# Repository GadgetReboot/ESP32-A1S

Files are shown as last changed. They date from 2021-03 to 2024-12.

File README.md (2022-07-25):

# ESP32-A1S
Breakout PCB for the ESP32-A1S module including an audio amp and basic GPIO headers, USB interface  
In Arduino IDE, the ESP32 board to choose is "ESP32 Dev Module"  
Use default configuration settings  
Then Enable PSRAM  <BR><BR>
The USB Micro-B connector on the board is GCT p/n USB3076-30-A   available from Digikey, Mouser etc

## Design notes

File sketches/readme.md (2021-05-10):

demo sketches to test EPS32-A1S module breakout board

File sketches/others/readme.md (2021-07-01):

Here are sketches that may be helpful to some, as presented here:<br>
https://github.com/GadgetReboot/ESP32-A1S/issues/1

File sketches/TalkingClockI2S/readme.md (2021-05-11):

ESP32 talking clock using the Talkie library to get the time over WiFi and speak it on the I2S audio chip

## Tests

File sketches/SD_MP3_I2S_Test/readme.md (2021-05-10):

List files on SD card and play mp3 files from root directory

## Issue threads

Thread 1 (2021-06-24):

Not an issue.

MichaelPNolan, 2021-06-24:
More like I want to say this was very helpful ... and I wish there was a place where I could link for others who want to learn using your code. I have written a more feature rich player moving on from the parts you put together to test playing mp3 from the card. Wondering if sharing my code so it's another sketch in your project is easier for others to find than trying to do my own video/links/github.

GadgetReboot, 2021-06-25:
> More like I want to say this was very helpful ... and I wish there was a place where I could link for others who want to learn using your code. I have written a more feature rich player moving on from the parts you put together to test playing mp3 from the card. Wondering if sharing my code so it's another sketch in your project is easier for others to find than trying to do my own video/links/github.

I'm glad it was helpful!  If you have a working demo sketch I could add it to the project examples for people to learn from.

MichaelPNolan, 2021-06-26:
Great - I've got a hack/continuation of your work
[SD_MP3_I2S_Hack02 .ino.txt](https://github.com/GadgetReboot/ESP32-A1S/files/6720121/SD_MP3_I2S_Hack02.ino.txt)
Rename to .ino
This a Hack02 version that can do FLAC and MP3 but the FLAC doesn't really work properly, its too slow ... or has noise. At least with the files I've tried so far. Something mentioned about running flac->loop(); to give it additional time to protest during the main program loop was mentioned. https://www.gitmemory.com/issue/earlephilhower/ESP8266Audio/301/686562378
That is where I was at when I uploaded.

There was a version before it that was just doing MP3 ...
[SD_MP3_I2S_Hack01.ino.txt](https://github.com/GadgetReboot/ESP32-A1S/files/6720123/SD_MP3_I2S_Hack01.ino.txt)
It might help people who want to make a music player. Best case for me is that ... more libraries get extended or ported from expressif ADF/IDF that might work. I've not made libraries in Arduino yet.

About me: I'm 52 and I started coding when I was 9. That doesn't mean I'm good at it - but i've been hacking this and that all my life in IT job. I was a musician as a trade for good portion of my life too ... which explains why I'm not a pro-software engineer.
I'm also making circuits but I've only ever done one PCB order from China for a pre-amp. I'm working on a headphone amp PCB .. and this is what leads me to an interest in DAC. I'm looking at making a midi master USB interface so I can play with the Marcel LIcence software and make hacks of that and ultimately I'd like to make a kind of hacked toy keyboard with a board in it that can be updated by wifi. I've written a VU meter for a single row of neopixel that takes a spectrum analysis fft but its a bit of a kludge. I'm usually trying to bring together past projects to make something that does everything.
I also do make videos on youtube but only getting started with any project like vids. Usually I just talk or make a lazy film of something I made to show friends.

I tried to make IDF/ADF environment work with my AI Thinker board but it just never really compiled for anything related to DAC. Too much time wasted. I had issues with Arduino until I really simplifed my library directory to just the least number of files for this to work. A lot of multiple library files errors before I did that.

GadgetReboot, 2021-07-01:
I've added the files here with a reference link back to this thread if it's useful to people
https://github.com/GadgetReboot/ESP32-A1S/tree/main/sketches/others
I will eventually try midi related things and I have several keyboards I can experiment with.

I'll probably make a pcb with a midi connector and isolation interface that can be connected to an Arduino as needed without dedicating it to a specific one so there's more flexibility.
20 years ago I'd probably be satisfied trying to place wires into midi connector pins and hope it holds up.

MichaelPNolan, 2021-07-01:
Thanks for that - yes, i had the pin connect hack days. I'm going to make my own arduino knock off before I try to implement something like an ESP32 dev board ... and I don't know where to start with surface mount and goo. That's why some of us have this mostly unsupported ESP32-A1S dev board. I've ordered some 16 bit DAC things so I can try with other boards sans AC101.

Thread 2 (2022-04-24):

Error in compiling

S144S, 2022-04-24:
Hi
Thanks for your helpful repo.
I was trying to test the example SD_MP3_I2S_TEST and I got this error:
"Error compiling for board ESP32 Dev Module."
I installed all required libraries, but I don't know where is the problem

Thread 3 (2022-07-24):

USB socket

bench2012, 2022-07-24:
Hi,

First of thanks for a very interesting board. I was going the same way, when I came across your project on GitHub. I managed to make a few board, but since there is no BOM list, just wonder which and where you got the usb socket? Usb socket could be a real pain to get right.

Many thx.

Bench

GadgetReboot, 2022-07-25:
The USB Micro-B connector on the board is GCT p/n USB3076-30-A   available from Digikey, Mouser etc

bench2012, 2022-07-25:
> The USB Micro-B connector on the board is GCT p/n USB3076-30-A available from Digikey, Mouser etc

Many thx. Will let you know how I get with this project. Again thanks for designing the board.

Closed 2022-07-25.

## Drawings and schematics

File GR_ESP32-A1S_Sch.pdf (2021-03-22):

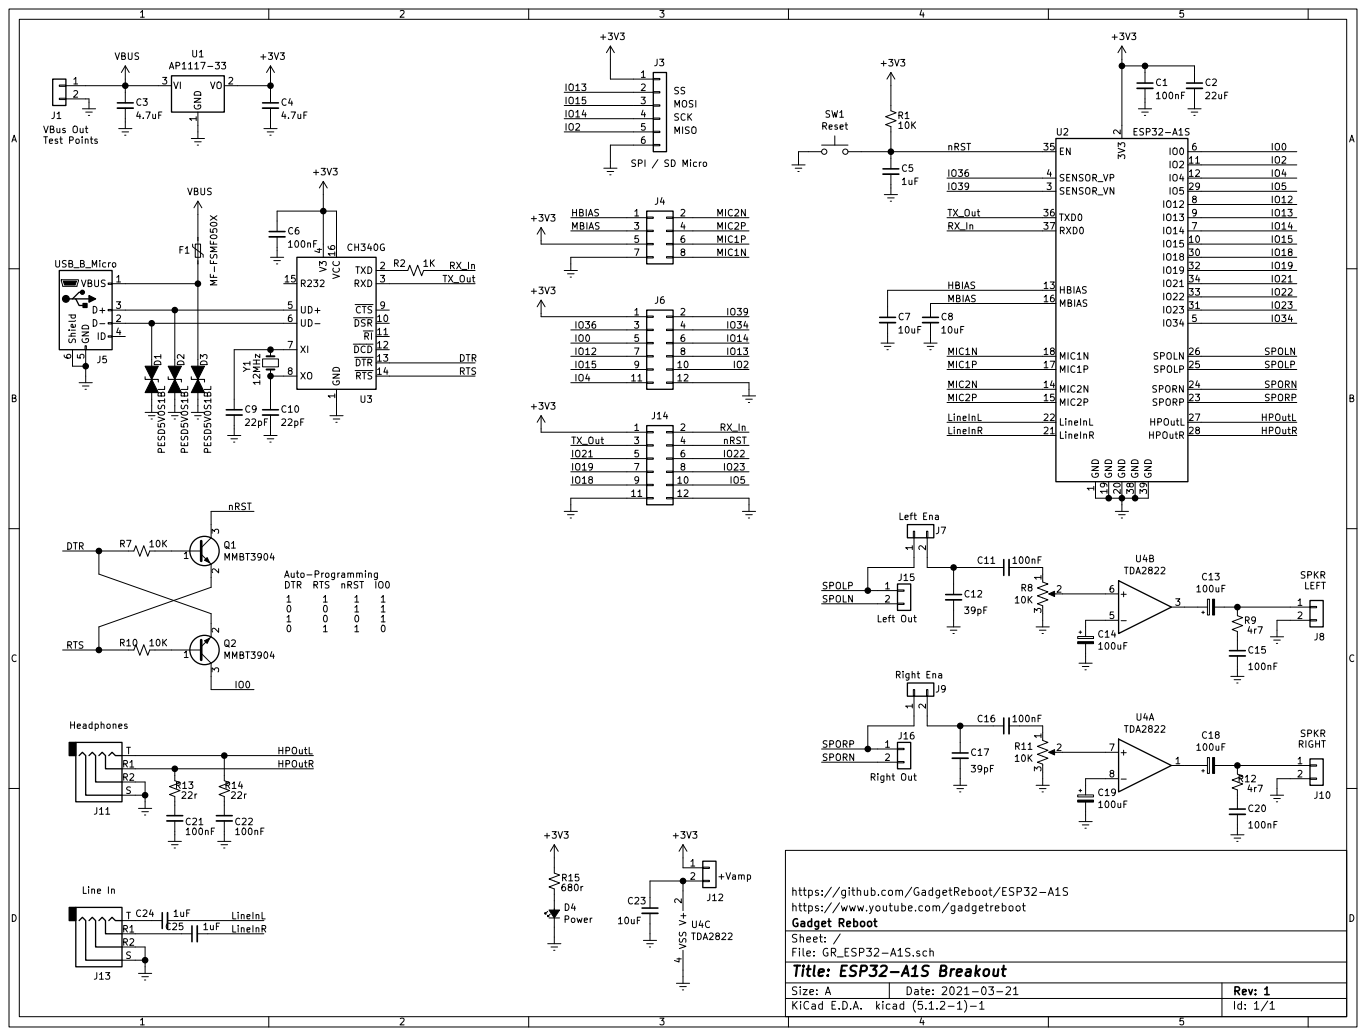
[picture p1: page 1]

1uF Auto-Programming DTR RTS nRST IO0

4 UD+ 5 UD- 6 XI 7 XO 8 CTS 9 U3 CH340G

1 DSR 10 RI 11 DCD 12 DTR 13 RTS 14 R232 15 VCC 16 TXD 2 RXD 3 V3

Left Ena Right Ena

Left Out Right Out

https://www.youtube.com/gadgetreboot
File: GR_ESP32-A1S.sch Sheet: / Gadget Reboot

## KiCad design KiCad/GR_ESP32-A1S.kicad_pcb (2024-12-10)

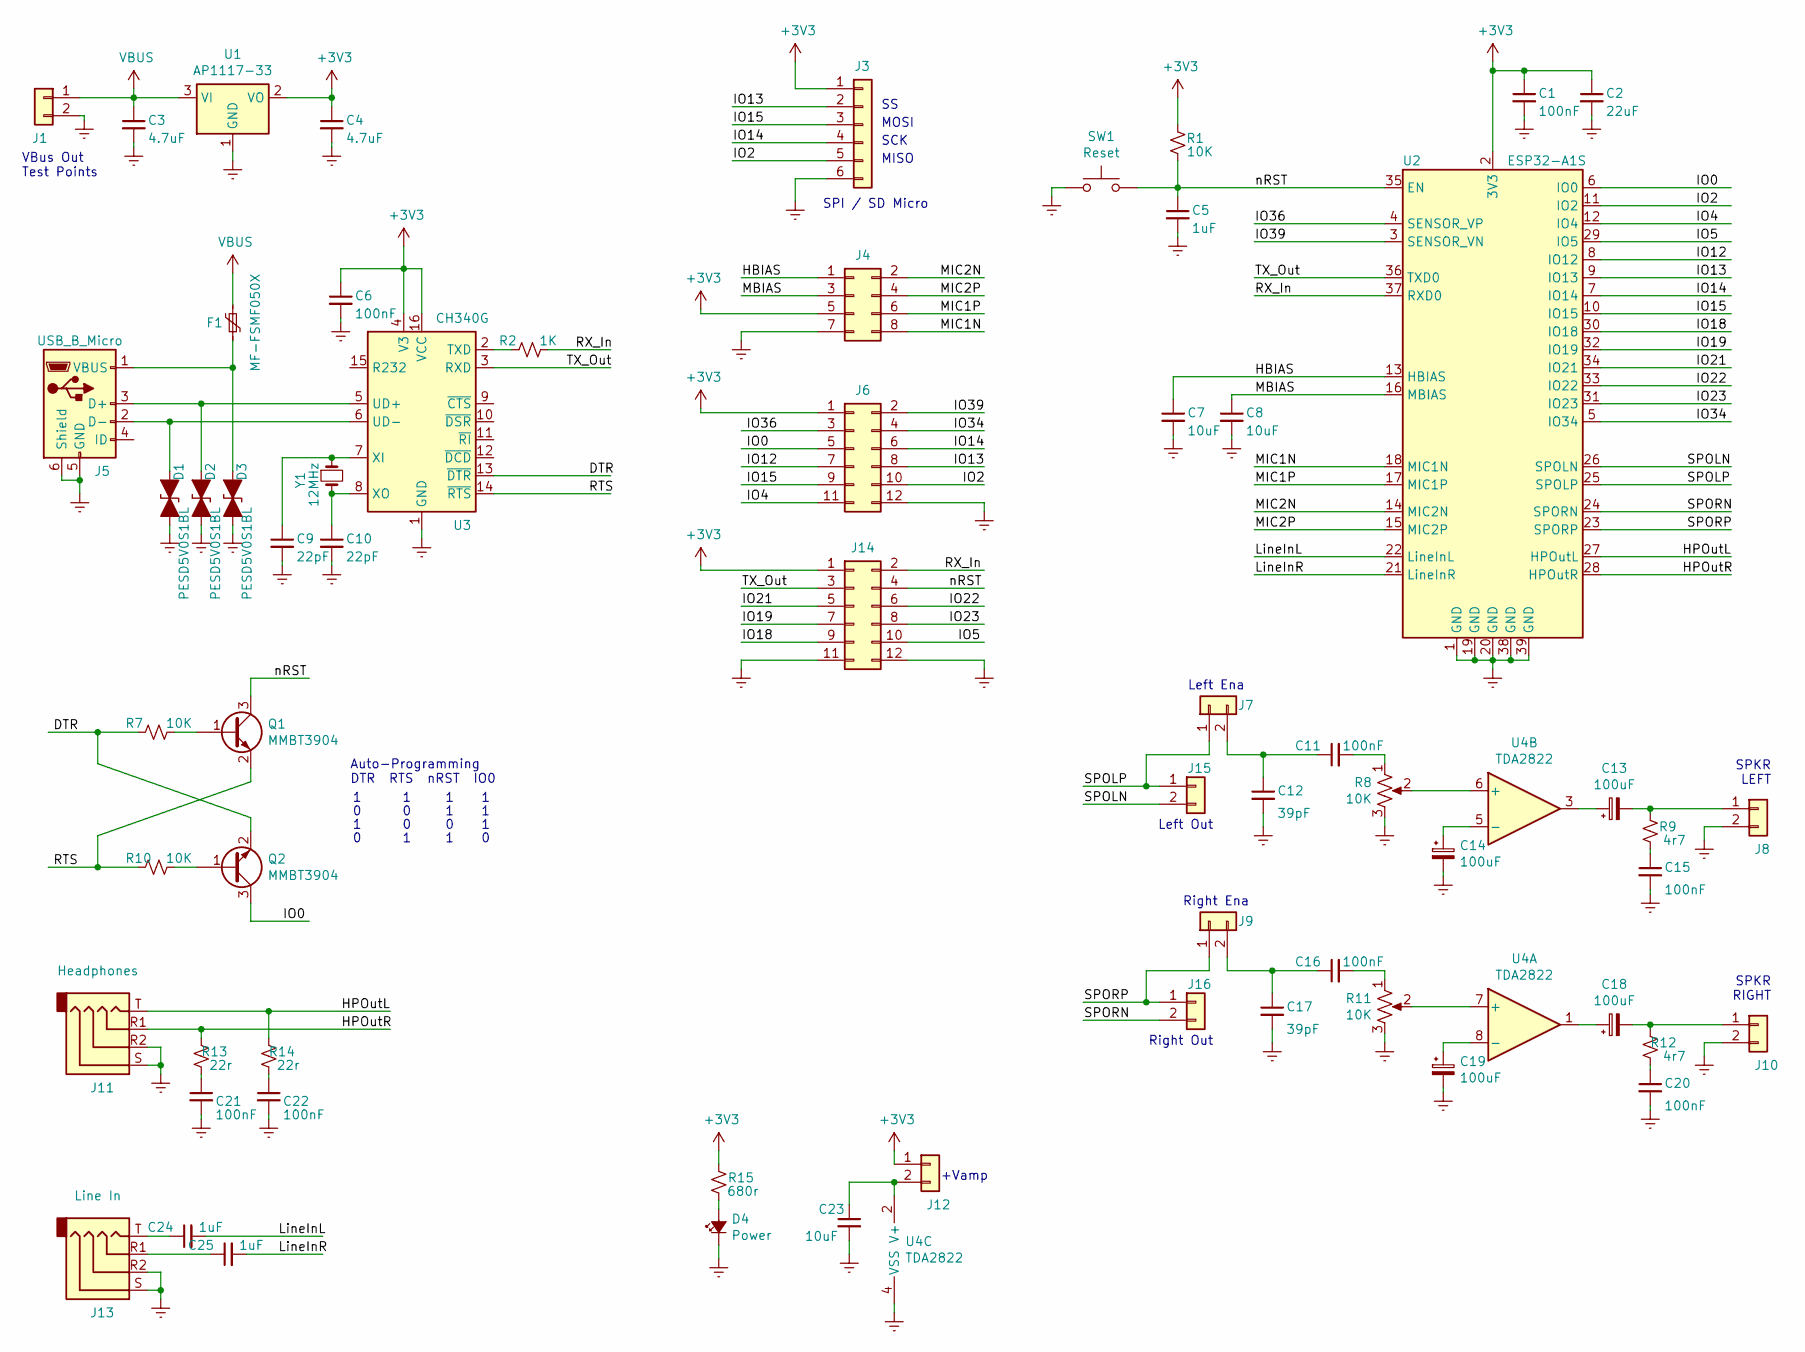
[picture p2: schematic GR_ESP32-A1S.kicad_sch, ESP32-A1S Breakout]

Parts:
C1, C6, C11, C15, C16, C20, C21, C22: 100nF; C_0805_2012Metric_Pad1.15x1.40mm_HandSolder
C2: 22uF; C_0805_2012Metric_Pad1.15x1.40mm_HandSolder
C3, C4: 4.7uF; C_0805_2012Metric_Pad1.15x1.40mm_HandSolder
C5, C24, C25: 1uF; C_0805_2012Metric_Pad1.15x1.40mm_HandSolder
C7, C8, C23: 10uF; C_0805_2012Metric_Pad1.15x1.40mm_HandSolder
C9, C10: 22pF; C_0805_2012Metric_Pad1.15x1.40mm_HandSolder
C12, C17: 39pF; C_0805_2012Metric_Pad1.15x1.40mm_HandSolder
C13, C14, C18, C19: 100uF; CP_Radial_D5.0mm_P2.50mm
D1, D2, D3: PESD5V0S1BL; SOD-882
D4: Power; LED_0805_2012Metric_Pad1.15x1.40mm_HandSolder
F1: MF-FSMF050X; R_0603_1608Metric_Pad1.05x0.95mm_HandSolder
J1, J7, J8, J9, J10, J12, J15, J16: Conn_01x02; PinHeader_1x02_P2.54mm_Vertical
J3: SPI; PinHeader_1x06_P2.54mm_Vertical
J4: Conn_02x04_Odd_Even; PinHeader_2x04_P2.54mm_Vertical
J5: USB_B_Micro; USB_Micro-B_GCT_USB3076-30-A
J6, J14: Conn_02x06_Odd_Even; PinHeader_2x06_P2.54mm_Vertical
J11: Headphones; Jack_3.5mm_PJ320D_Horizontal
J13: Line In; Jack_3.5mm_PJ320D_Horizontal
Q1, Q2: MMBT3904; SOT-23
R1, R7, R10: 10K; R_0805_2012Metric_Pad1.15x1.40mm_HandSolder
R2: 1K; R_0805_2012Metric_Pad1.15x1.40mm_HandSolder
R8, R11: 10K; Potentiometer_Vishay_T73YP_Vertical
R9, R12: 4r7; R_0805_2012Metric_Pad1.15x1.40mm_HandSolder
R13, R14: 22r; R_0805_2012Metric_Pad1.15x1.40mm_HandSolder
R15: 680r; R_0805_2012Metric_Pad1.15x1.40mm_HandSolder
SW1: Reset; SW_SPST_FSMSM
U1: AP1117-33; SOT-223-3_TabPin2
U2: ESP32-A1S
U3: CH340G; SOIC-16_3.9x9.9mm_P1.27mm
U4: TDA2822; SOIC-8_3.9x4.9mm_P1.27mm
Y1: 12MHz; Crystal_SMD_HC49-SD_HandSoldering

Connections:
+3V3: C1.1, C2.1, C4.1, C6.1, J3.1, J4.5, J6.1, J12.1, J14.1, R1.1, R15.1, U1.2 (VO), U2.2 (3V3), U3.4 (V3), U3.16 (VCC)
/DTR: Q2.2 (E), R7.1, U3.13 (~DTR)
/HBIAS: C7.1, J4.1, U2.13 (HBIAS)
/HPOutL: J11.T, R14.1, U2.27 (HPOutL)
/HPOutR: J11.R1, R13.1, U2.28 (HPOutR)
/IO0: J6.5, Q2.3 (C), U2.6 (IO0)
/IO2: J3.5, J6.10, U2.11 (IO2)
/IO4: J6.11, U2.12 (IO4)
/IO5: J14.10, U2.29 (IO5)
/IO12: J6.7, U2.8 (IO12)
/IO13: J3.2, J6.8, U2.9 (IO13)
/IO14: J3.4, J6.6, U2.7 (IO14)
/IO15: J3.3, J6.9, U2.10 (IO15)
/IO18: J14.9, U2.30 (IO18)
/IO19: J14.7, U2.32 (IO19)
/IO21: J14.5, U2.34 (IO21)
/IO22: J14.6, U2.33 (IO22)
/IO23: J14.8, U2.31 (IO23)
/IO34: J6.4, U2.5 (IO34)
/IO36: J6.3, U2.4 (SENSOR_VP)
/IO39: J6.2, U2.3 (SENSOR_VN)
/LineInL: C24.2, U2.22 (LineInL)
/LineInR: C25.2, U2.21 (LineInR)
/MBIAS: C8.1, J4.3, U2.16 (MBIAS)
/MIC1N: J4.8, U2.18 (MIC1N)
/MIC1P: J4.6, U2.17 (MIC1P)
/MIC2N: J4.2, U2.14 (MIC2N)
/MIC2P: J4.4, U2.15 (MIC2P)
/RTS: Q1.2 (E), R10.1, U3.14 (~RTS)
/RX_In: J14.2, R2.2, U2.37 (RXD0)
/SPOLN: J15.2, U2.26 (SPOLN)
/SPOLP: J7.1, J15.1, U2.25 (SPOLP)
/SPORN: J16.2, U2.24 (SPORN)
/SPORP: J9.1, J16.1, U2.23 (SPORP)
/TX_Out: J14.3, U2.36 (TXD0), U3.3 (RXD)
/nRST: C5.1, J14.4, Q1.3 (C), R1.2, SW1.2, U2.35 (EN)
GNDREF: C1.2, C2.2, C3.2, C4.2, C5.2, C6.2, C7.2, C8.2, C9.2, C10.2, C12.2, C14.2, C15.2, C17.2, C19.2, C20.2, C21.2, C22.2, C23.2, D1.2 (A2), D2.2 (A2), D3.2 (A2), D4.1 (K), J1.2, J3.6, J4.7, J5.5 (GND), J5.6 (Shield), J6.12, J8.2, J10.2, J11.R2, J11.S, J13.R2, J13.S, J14.11, J14.12, R8.3, R11.3, SW1.1, U1.1 (GND), U2.1 (GND), U2.19 (GND), U2.20 (GND), U2.38 (GND), U2.39 (GND), U3.1 (GND), U4.4 (VSS)
unnamed: C9.1, U3.7 (XI), Y1.1
unnamed: C10.1, U3.8 (XO), Y1.2
unnamed: C11.1, C12.1, J7.2
unnamed: C11.2, R8.1
unnamed: C13.1, U4.3
unnamed: C13.2, J8.1, R9.1
unnamed: C14.1, U4.5 (-)
unnamed: C15.1, R9.2
unnamed: C16.1, C17.1, J9.2
unnamed: C16.2, R11.1
unnamed: C18.1, U4.1
unnamed: C18.2, J10.1, R12.1
unnamed: C19.1, U4.8 (-)
unnamed: C20.1, R12.2
unnamed: C21.1, R13.2
unnamed: C22.1, R14.2
unnamed: C23.1, J12.2, U4.2 (V+)
unnamed: C24.1, J13.T
unnamed: C25.1, J13.R1
unnamed: D1.1 (A1), J5.2 (D-), U3.6 (UD-)
unnamed: D2.1 (A1), J5.3 (D+), U3.5 (UD+)
unnamed: D4.2 (A), R15.2
unnamed: Q1.1 (B), R7.2
unnamed: Q2.1 (B), R10.2
unnamed: R2.1, U3.2 (TXD)
unnamed: R8.2, U4.6 (+)
unnamed: R11.2, U4.7 (+)

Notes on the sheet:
Left Out
1 0 0 1
Right Ena
SPKR RIGHT
SPKR LEFT
SPI / SD Micro
Right Out
+Vamp
MISO
0 0 1 1
1 1 1 1
MOSI
Auto-Programming DTR RTS nRST IO0
Left Ena
SCK
0 1 1 0
VBus Out Test Points

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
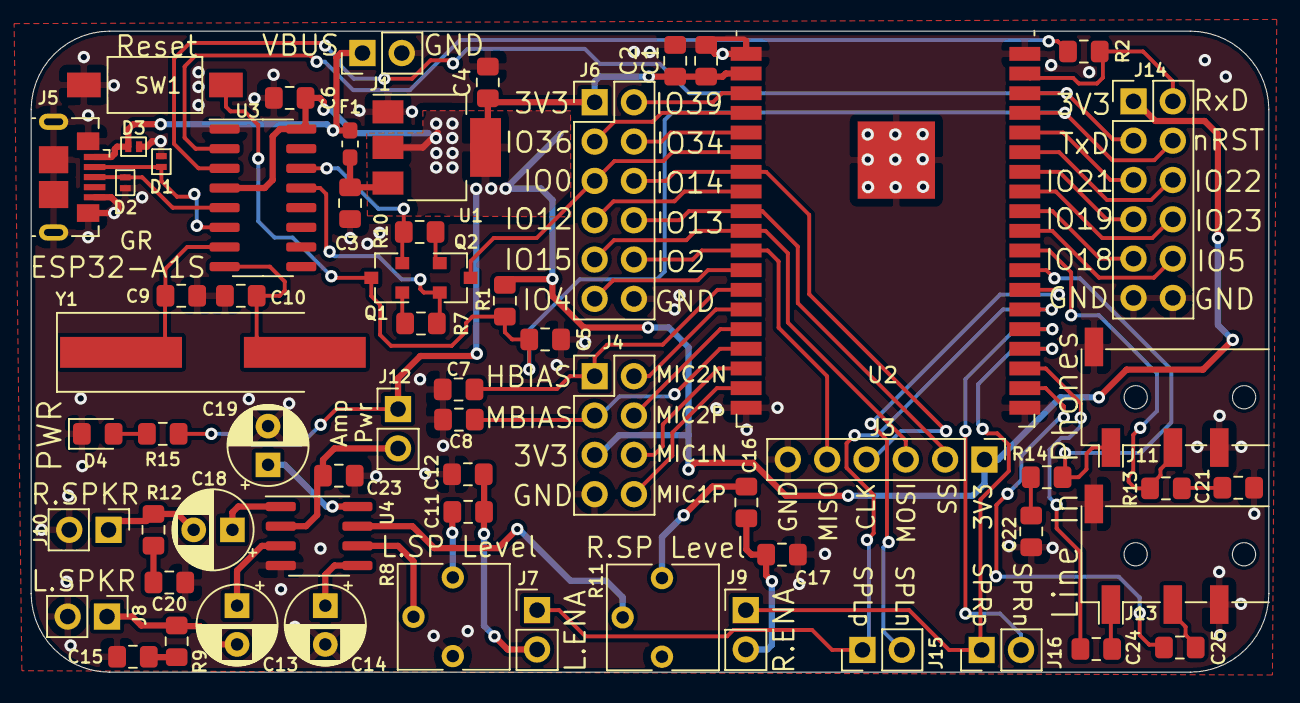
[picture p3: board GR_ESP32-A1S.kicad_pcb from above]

Board: 2 copper layers, 79.9 x 41.4 mm, 64 parts (0 on the bottom side), 66 nets.

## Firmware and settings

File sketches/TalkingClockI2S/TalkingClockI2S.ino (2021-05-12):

// Talking Clock example, with speech taken from
// https://github.com/going-digital/Talkie/blob/master/Talkie/examples/Vocab_US_Clock/Vocab_US_Clock.ino
// Released under GPL v2

#ifdef ESP32
    #include <WiFi.h>
#else
    #include <ESP8266WiFi.h>
#endif

#include <time.h>
#include "AudioFileSourcePROGMEM.h"
#include "AudioGeneratorTalkie.h"
#include "AudioOutputI2S.h"
#include "AC101.h"

#define IIS_SCLK                    27
#define IIS_LCLK                    26
#define IIS_DSIN                    25

#define IIC_CLK                     32
#define IIC_DATA                    33

#ifndef STASSID
#define STASSID "yourSSID"
#define STAPSK  "yourPASS"
#endif

static AC101 ac;

const char *ssid = STASSID;
const char *pass = STAPSK;

long timezone = -5;
byte daysavetime = 1;

uint8_t spTHE[]       PROGMEM = {0x08,0xE8,0x3E,0x55,0x01,0xC3,0x86,0x27,0xAF,0x72,0x0D,0x4D,0x97,0xD5,0xBC,0x64,0x3C,0xF2,0x5C,0x51,0xF1,0x93,0x36,0x8F,0x4F,0x59,0x2A,0x42,0x7A,0x32,0xC3,0x64,0xFF,0x3F};
uint8_t spTIME[]      PROGMEM = {0x0E,0x28,0xAC,0x2D,0x01,0x5D,0xB6,0x0D,0x33,0xF3,0x54,0xB3,0x60,0xBA,0x8C,0x54,0x5C,0xCD,0x2D,0xD4,0x32,0x73,0x0F,0x8E,0x34,0x33,0xCB,0x4A,0x25,0xD4,0x25,0x83,0x2C,0x2B,0xD5,0x50,0x97,0x08,0x32,0xEC,0xD4,0xDC,0x4C,0x33,0xC8,0x70,0x73,0x0F,0x33,0xCD,0x20,0xC3,0xCB,0x43,0xDD,0x3C,0xCD,0x8C,0x20,0x77,0x89,0xF4,0x94,0xB2,0xE2,0xE2,0x35,0x22,0x5D,0xD6,0x4A,0x8A,0x96,0xCC,0x36,0x25,0x2D,0xC9,0x9A,0x7B,0xC2,0x18,0x87,0x24,0x4B,0x1C,0xC9,0x50,0x19,0x92,0x2C,0x71,0x34,0x4B,0x45,0x8A,0x8B,0xC4,0x96,0xB6,0x5A,0x29,0x2A,0x92,0x5A,0xCA,0x53,0x96,0x20,0x05,0x09,0xF5,0x92,0x5D,0xBC,0xE8,0x58,0x4A,0xDD,0xAE,0x73,0xBD,0x65,0x4B,0x8D,0x78,0xCA,0x2B,0x4E,0xD8,0xD9,0xED,0x22,0x20,0x06,0x75,0x00,0x00,0x80,0xFF,0x07};
uint8_t spIS[]        PROGMEM = {0x21,0x18,0x96,0x38,0xB7,0x14,0x8D,0x60,0x3A,0xA6,0xE8,0x51,0xB4,0xDC,0x2E,0x48,0x7B,0x5A,0xF1,0x70,0x1B,0xA3,0xEC,0x09,0xC6,0xCB,0xEB,0x92,0x3D,0xA7,0x69,0x1F,0xAF,0x71,0x89,0x9C,0xA2,0xB3,0xFC,0xCA,0x35,0x72,0x9A,0xD1,0xF0,0xAB,0x12,0xB3,0x2B,0xC6,0xCD,0x4F,0xCC,0x32,0x26,0x19,0x07,0xDF,0x0B,0x8F,0xB8,0xA4,0xED,0x7C,0xCF,0x23,0x62,0x8B,0x8E,0xF1,0x23,0x0A,0x8B,0x6E,0xCB,0xCE,0xEF,0x54,0x44,0x3C,0xDC,0x08,0x60,0x0B,0x37,0x01,0x1C,0x53,0x26,0x80,0x15,0x4E,0x14,0xB0,0x54,0x2B,0x02,0xA4,0x69,0xFF,0x7F};
uint8_t spA_M_[]      PROGMEM = {0xCD,0xEF,0x86,0xAB,0x57,0x6D,0x0F,0xAF,0x71,0xAD,0x49,0x55,0x3C,0xFC,0x2E,0xC5,0xB7,0x5C,0xF1,0xF2,0x87,0x66,0xDD,0x4E,0xC5,0xC3,0xEF,0x92,0xE2,0x3A,0x65,0xB7,0xA0,0x09,0xAA,0x1B,0x97,0x54,0x82,0x2E,0x28,0x77,0x5C,0x52,0x09,0x1A,0xA3,0xB8,0x76,0x49,0x25,0x68,0x8C,0x73,0xDB,0x24,0x95,0xA0,0x32,0xA9,0x6B,0xA7,0xD9,0x82,0x26,0xA9,0x76,0x42,0xD6,0x08,0xBA,0xE1,0xE8,0x0E,0x5A,0x2B,0xEA,0x9E,0x3D,0x27,0x18,0xAD,0xA8,0x07,0xF1,0x98,0x90,0x35,0xA2,0x96,0x44,0xA3,0x5D,0x66,0x8B,0x6B,0x12,0xCD,0x32,0x85,0x25,0xC9,0x81,0x2D,0xC3,0x64,0x85,0x34,0x58,0x89,0x94,0x52,0x1C,0x52,0x2F,0x35,0xDA,0xC7,0x51,0x48,0x23,0x97,0xCC,0x2C,0x97,0x2E,0xF3,0x5C,0xF3,0xA2,0x14,0xBA,0x2C,0x48,0xCE,0xCA,0x76,0xE8,0x32,0x2F,0x34,0xB2,0xDB,0x85,0xC9,0x83,0x90,0xA8,0x2C,0x57,0x26,0x8F,0x9C,0xBD,0xA2,0x53,0xD9,0xC2,0x54,0x59,0x28,0x99,0x4B,0x2C,0x5D,0xFF,0x3F};
uint8_t spP_M_[]      PROGMEM = {0x0E,0x98,0x41,0x54,0x00,0x43,0xA0,0x05,0xAB,0x42,0x8E,0x1D,0xA3,0x15,0xEC,0x4E,0x58,0xF7,0x92,0x66,0x70,0x1B,0x66,0xDB,0x73,0x99,0xC1,0xEB,0x98,0xED,0xD6,0x25,0x25,0x6F,0x70,0x92,0xDD,0x64,0xD8,0xFC,0x61,0xD0,0x66,0x83,0xD6,0x0A,0x86,0x23,0xAB,0x69,0xDA,0x2B,0x18,0x9E,0x3D,0x37,0x69,0x9D,0xA8,0x07,0x71,0x9F,0xA0,0xBD,0xA2,0x16,0xD5,0x7C,0x54,0xF6,0x88,0x6B,0x54,0x8B,0x34,0x49,0x2D,0x29,0x49,0x3C,0x34,0x64,0xA5,0x24,0x1B,0x36,0xD7,0x72,0x13,0x92,0xA4,0xC4,0x2D,0xC3,0xB3,0x4B,0xA3,0x62,0x0F,0x2B,0x37,0x6E,0x8B,0x5A,0xD4,0x3D,0xDD,0x9A,0x2D,0x50,0x93,0xF6,0x4C,0xAA,0xB6,0xC4,0x85,0x3B,0xB2,0xB1,0xD8,0x93,0x20,0x4D,0x8F,0x24,0xFF,0x0F};
uint8_t spOH[]        PROGMEM = {0xC6,0xC9,0x71,0x5A,0xA2,0x92,0x14,0x2F,0x6E,0x97,0x9C,0x46,0x9D,0xDC,0xB0,0x4D,0x62,0x1B,0x55,0x70,0xDD,0x55,0xBE,0x0E,0x36,0xC1,0x33,0x37,0xA9,0xA7,0x51,0x1B,0xCF,0x3C,0xA5,0x9E,0x44,0xAC,0x3C,0x7D,0x98,0x7B,0x52,0x96,0x72,0x65,0x4B,0xF6,0x1A,0xD9,0xCA,0xF5,0x91,0x2D,0xA2,0x2A,0x4B,0xF7,0xFF,0x01};
uint8_t spOCLOCK[]    PROGMEM = {0x21,0x4E,0x3D,0xB8,0x2B,0x19,0xBB,0x24,0x0E,0xE5,0xEC,0x60,0xE4,0xF2,0x90,0x13,0xD4,0x2A,0x11,0x80,0x00,0x42,0x69,0x26,0x40,0xD0,0x2B,0x04,0x68,0xE0,0x4D,0x00,0x3A,0x35,0x35,0x33,0xB6,0x51,0xD9,0x64,0x34,0x82,0xB4,0x9A,0x63,0x92,0x55,0x89,0x52,0x5B,0xCA,0x2E,0x34,0x25,0x4E,0x63,0x28,0x3A,0x50,0x95,0x26,0x8D,0xE6,0xAA,0x64,0x58,0xEA,0x92,0xCE,0xC2,0x46,0x15,0x9B,0x86,0xCD,0x2A,0x2E,0x37,0x00,0x00,0x00,0x0C,0xC8,0xDD,0x05,0x01,0xB9,0x33,0x21,0xA0,0x74,0xD7,0xFF,0x07};
uint8_t spONE[]       PROGMEM = {0xCC,0x67,0x75,0x42,0x59,0x5D,0x3A,0x4F,0x9D,0x36,0x63,0xB7,0x59,0xDC,0x30,0x5B,0x5C,0x23,0x61,0xF3,0xE2,0x1C,0xF1,0xF0,0x98,0xC3,0x4B,0x7D,0x39,0xCA,0x1D,0x2C,0x2F,0xB7,0x15,0xEF,0x70,0x79,0xBC,0xD2,0x46,0x7C,0x52,0xE5,0xF1,0x4A,0x6A,0xB3,0x71,0x47,0xC3,0x2D,0x39,0x34,0x4B,0x23,0x35,0xB7,0x7A,0x55,0x33,0x8F,0x59,0xDC,0xA2,0x44,0xB5,0xBC,0x66,0x72,0x8B,0x64,0xF5,0xF6,0x98,0xC1,0x4D,0x42,0xD4,0x27,0x62,0x38,0x2F,0x4A,0xB6,0x9C,0x88,0x68,0xBC,0xA6,0x95,0xF8,0x5C,0xA1,0x09,0x86,0x77,0x91,0x11,0x5B,0xFF,0x0F};
uint8_t spTWO[]       PROGMEM = {0x0E,0x38,0x6E,0x25,0x00,0xA3,0x0D,0x3A,0xA0,0x37,0xC5,0xA0,0x05,0x9E,0x56,0x35,0x86,0xAA,0x5E,0x8C,0xA4,0x82,0xB2,0xD7,0x74,0x31,0x22,0x69,0xAD,0x1C,0xD3,0xC1,0xD0,0xFA,0x28,0x2B,0x2D,0x47,0xC3,0x1B,0xC2,0xC4,0xAE,0xC6,0xCD,0x9C,0x48,0x53,0x9A,0xFF,0x0F};
uint8_t spTHREE[]     PROGMEM = {0x02,0xD8,0x2E,0x9C,0x01,0xDB,0xA6,0x33,0x60,0xFB,0x30,0x01,0xEC,0x20,0x12,0x8C,0xE4,0xD8,0xCA,0x32,0x96,0x73,0x63,0x41,0x39,0x89,0x98,0xC1,0x4D,0x0D,0xED,0xB0,0x2A,0x05,0x37,0x0F,0xB4,0xA5,0xAE,0x5C,0xDC,0x36,0xD0,0x83,0x2F,0x4A,0x71,0x7B,0x03,0xF7,0x38,0x59,0xCD,0xED,0x1E,0xB4,0x6B,0x14,0x35,0xB7,0x6B,0x94,0x99,0x91,0xD5,0xDC,0x26,0x48,0x77,0x4B,0x66,0x71,0x1B,0x21,0xDB,0x2D,0x8A,0xC9,0x6D,0x88,0xFC,0x26,0x28,0x3A,0xB7,0x21,0xF4,0x1F,0xA3,0x65,0xBC,0x02,0x38,0xBB,0x3D,0x8E,0xF0,0x2B,0xE2,0x08,0xB7,0x34,0xFF,0x0F};
uint8_t spFOUR[]      PROGMEM = {0x0C,0x18,0xB6,0x9A,0x01,0xC3,0x75,0x09,0x60,0xD8,0x0E,0x09,0x30,0xA0,0x9B,0xB6,0xA0,0xBB,0xB0,0xAA,0x16,0x4E,0x82,0xEB,0xEA,0xA9,0xFA,0x59,0x49,0x9E,0x59,0x23,0x9A,0x27,0x3B,0x78,0x66,0xAE,0x4A,0x9C,0x9C,0xE0,0x99,0xD3,0x2A,0xBD,0x72,0x92,0xEF,0xE6,0x88,0xE4,0x45,0x4D,0x7E,0x98,0x2D,0x62,0x67,0x37,0xF9,0xA1,0x37,0xA7,0x6C,0x94,0xE4,0xC7,0x1E,0xDC,0x3C,0xA5,0x83,0x1F,0x8B,0xEB,0x52,0x0E,0x0E,0x7E,0x2E,0x4E,0xC7,0x31,0xD2,0x79,0xA5,0x3A,0x0D,0xD9,0xC4,0xFF,0x07};
uint8_t spFIVE[]      PROGMEM = {0x02,0xE8,0x3E,0x8C,0x01,0xDD,0x65,0x08,0x60,0x98,0x4C,0x06,0x34,0x93,0xCE,0x80,0xE6,0xDA,0x9A,0x14,0x6B,0xAA,0x47,0xD1,0x5E,0x56,0xAA,0x6D,0x56,0xCD,0x78,0xD9,0xA9,0x1C,0x67,0x05,0x83,0xE1,0xA4,0xBA,0x38,0xEE,0x16,0x86,0x9B,0xFA,0x60,0x87,0x5B,0x18,0x6E,0xEE,0x8B,0x1D,0x6E,0x61,0xB9,0x69,0x36,0x65,0xBA,0x8D,0xE5,0xE5,0x3E,0x1C,0xE9,0x0E,0x96,0x9B,0x5B,0xAB,0x95,0x2B,0x58,0x6E,0xCE,0xE5,0x3A,0x6A,0xF3,0xB8,0x35,0x84,0x7B,0x05,0xA3,0xE3,0x36,0xEF,0x92,0x19,0xB4,0x86,0xDB,0xB4,0x69,0xB4,0xD1,0x2A,0x4E,0x65,0x9A,0x99,0xCE,0x28,0xD9,0x85,0x71,0x4C,0x18,0x6D,0x67,0x47,0xC6,0x5E,0x53,0x4A,0x9C,0xB5,0xE2,0x85,0x45,0x26,0xFE,0x7F};
uint8_t spSIX[]       PROGMEM = {0x0E,0xD8,0xAE,0xDD,0x03,0x0E,0x38,0xA6,0xD2,0x01,0xD3,0xB4,0x2C,0xAD,0x6A,0x35,0x9D,0xB1,0x7D,0xDC,0xEE,0xC4,0x65,0xD7,0xF1,0x72,0x47,0x24,0xB3,0x19,0xD9,0xD9,0x05,0x70,0x40,0x49,0xEA,0x02,0x98,0xBE,0x42,0x01,0xDF,0xA4,0x69,0x40,0x00,0xDF,0x95,0xFC,0x3F};
uint8_t spSEVEN[]     PROGMEM = {0x02,0xB8,0x3A,0x8C,0x01,0xDF,0xA4,0x73,0x40,0x01,0x47,0xB9,0x2F,0x33,0x3B,0x73,0x5F,0x53,0x7C,0xEC,0x9A,0xC5,0x63,0xD5,0xD1,0x75,0xAE,0x5B,0xFC,0x64,0x5C,0x35,0x87,0x91,0xF1,0x83,0x36,0xB5,0x68,0x55,0xC5,0x6F,0xDA,0x45,0x2D,0x1C,0x2D,0xB7,0x38,0x37,0x9F,0x60,0x3C,0xBC,0x9A,0x85,0xA3,0x25,0x66,0xF7,0x8A,0x57,0x1C,0xA9,0x67,0x56,0xCA,0x5E,0xF0,0xB2,0x16,0xB2,0xF1,0x89,0xCE,0x8B,0x92,0x25,0xC7,0x2B,0x33,0xCF,0x48,0xB1,0x99,0xB4,0xF3,0xFF};
uint8_t spEIGHT[]     PROGMEM = {0xC3,0x6C,0x86,0xB3,0x27,0x6D,0x0F,0xA7,0x48,0x99,0x4E,0x55,0x3C,0xBC,0x22,0x65,0x36,0x4D,0xD1,0xF0,0x32,0xD3,0xBE,0x34,0xDA,0xC3,0xEB,0x82,0xE2,0xDA,0x65,0x35,0xAF,0x31,0xF2,0x6B,0x97,0x95,0xBC,0x86,0xD8,0x6F,0x82,0xA6,0x73,0x0B,0xC6,0x9E,0x72,0x99,0xCC,0xCB,0x02,0xAD,0x3C,0x9A,0x10,0x60,0xAB,0x62,0x05,0x2C,0x37,0x84,0x00,0xA9,0x73,0x00,0x00,0xFE,0x1F};
uint8_t spNINE[]      PROGMEM = {0xCC,0xA1,0x26,0xBB,0x83,0x93,0x18,0xCF,0x4A,0xAD,0x2E,0x31,0xED,0x3C,0xA7,0x24,0x26,0xC3,0x54,0xF1,0x92,0x64,0x8B,0x8A,0x98,0xCB,0x2B,0x2E,0x34,0x53,0x2D,0x0E,0x2F,0x57,0xB3,0x0C,0x0D,0x3C,0xBC,0x3C,0x4C,0x4B,0xCA,0xF4,0xF0,0x72,0x0F,0x6E,0x49,0x53,0xCD,0xCB,0x53,0x2D,0x35,0x4D,0x0F,0x2F,0x0F,0xD7,0x0C,0x0D,0x3D,0xBC,0xDC,0x4D,0xD3,0xDD,0xC2,0xF0,0x72,0x52,0x4F,0x57,0x9B,0xC3,0xAB,0x89,0xBD,0x42,0x2D,0x0F,0xAF,0x5A,0xD1,0x71,0x91,0x55,0xBC,0x2C,0xC5,0x3B,0xD8,0x65,0xF2,0x82,0x94,0x18,0x4E,0x3B,0xC1,0x73,0x42,0x32,0x33,0x15,0x45,0x4F,0x79,0x52,0x6A,0x55,0xA6,0xA3,0xFF,0x07};
uint8_t spTEN[]       PROGMEM = {0x0E,0xD8,0xB1,0xDD,0x01,0x3D,0xA8,0x24,0x7B,0x04,0x27,0x76,0x77,0xDC,0xEC,0xC2,0xC5,0x23,0x84,0xCD,0x72,0x9A,0x51,0xF7,0x62,0x45,0xC7,0xEB,0x4E,0x35,0x4A,0x14,0x2D,0xBF,0x45,0xB6,0x0A,0x75,0xB8,0xFC,0x16,0xD9,0x2A,0xD9,0xD6,0x0A,0x5A,0x10,0xCD,0xA2,0x48,0x23,0xA8,0x81,0x35,0x4B,0x2C,0xA7,0x20,0x69,0x0A,0xAF,0xB6,0x15,0x82,0xA4,0x29,0x3C,0xC7,0x52,0x08,0xA2,0x22,0xCF,0x68,0x4B,0x2E,0xF0,0x8A,0xBD,0xA3,0x2C,0xAB,0x40,0x1B,0xCE,0xAA,0xB2,0x6C,0x82,0x40,0x4D,0x7D,0xC2,0x89,0x88,0x8A,0x61,0xCC,0x74,0xD5,0xFF,0x0F};
uint8_t spELEVEN[]    PROGMEM = {0xC3,0xCD,0x76,0x5C,0xAE,0x14,0x0F,0x37,0x9B,0x71,0xDE,0x92,0x55,0xBC,0x2C,0x27,0x70,0xD3,0x76,0xF0,0x83,0x5E,0xA3,0x5E,0x5A,0xC1,0xF7,0x61,0x58,0xA7,0x19,0x35,0x3F,0x99,0x31,0xDE,0x52,0x74,0xFC,0xA2,0x26,0x64,0x4B,0xD1,0xF1,0xAB,0xAE,0xD0,0x2D,0xC5,0xC7,0x2F,0x36,0xDD,0x27,0x15,0x0F,0x3F,0xD9,0x08,0x9F,0x62,0xE4,0xC2,0x2C,0xD4,0xD8,0xD3,0x89,0x0B,0x1B,0x57,0x11,0x0B,0x3B,0xC5,0xCF,0xD6,0xCC,0xC6,0x64,0x35,0xAF,0x18,0x73,0x1F,0xA1,0x5D,0xBC,0x62,0x45,0xB3,0x45,0x51,0xF0,0xA2,0x62,0xAB,0x4A,0x5B,0xC9,0x4B,0x8A,0x2D,0xB3,0x6C,0x06,0x2F,0x29,0xB2,0xAC,0x8A,0x18,0xBC,0x28,0xD9,0xAA,0xD2,0x92,0xF1,0xBC,0xE0,0x98,0x8C,0x48,0xCC,0x17,0x52,0xA3,0x27,0x6D,0x93,0xD0,0x4B,0x8E,0x0E,0x77,0x02,0x00,0xFF,0x0F};
uint8_t spTWELVE[]    PROGMEM = {0x06,0x28,0x46,0xD3,0x01,0x25,0x06,0x13,0x20,0xBA,0x70,0x70,0xB6,0x79,0xCA,0x36,0xAE,0x28,0x38,0xE1,0x29,0xC5,0x35,0xA3,0xE6,0xC4,0x16,0x6A,0x53,0x8C,0x97,0x9B,0x72,0x86,0x4F,0x28,0x1A,0x6E,0x0A,0x59,0x36,0xAE,0x68,0xF8,0x29,0x67,0xFA,0x06,0xA3,0x16,0xC4,0x96,0xE6,0x53,0xAC,0x5A,0x9C,0x56,0x72,0x77,0x31,0x4E,0x49,0x5C,0x8D,0x5B,0x29,0x3B,0x24,0x61,0x1E,0x6C,0x9B,0x6C,0x97,0xF8,0xA7,0x34,0x19,0x92,0x4C,0x62,0x9E,0x72,0x65,0x58,0x12,0xB1,0x7E,0x09,0xD5,0x2E,0x53,0xC5,0xBA,0x36,0x6B,0xB9,0x2D,0x17,0x05,0xEE,0x9A,0x6E,0x8E,0x05,0x50,0x6C,0x19,0x07,0x18,0x50,0xBD,0x3B,0x01,0x92,0x08,0x41,0x40,0x10,0xA6,0xFF,0x0F};
uint8_t spTHIRTEEN[]  PROGMEM = {0x08,0xE8,0x2C,0x15,0x01,0x43,0x07,0x13,0xE0,0x98,0xB4,0xA6,0x35,0xA9,0x1E,0xDE,0x56,0x8E,0x53,0x9C,0x7A,0xE7,0xCA,0x5E,0x76,0x8D,0x94,0xE5,0x2B,0xAB,0xD9,0xB5,0x62,0xA4,0x9C,0xE4,0xE6,0xB4,0x41,0x1E,0x7C,0xB6,0x93,0xD7,0x16,0x99,0x5A,0xCD,0x61,0x76,0x55,0xC2,0x91,0x61,0x1B,0xC0,0x01,0x5D,0x85,0x05,0xE0,0x68,0x51,0x07,0x1C,0xA9,0x64,0x80,0x1D,0x4C,0x9C,0x95,0x88,0xD4,0x04,0x3B,0x4D,0x4E,0x21,0x5C,0x93,0xA8,0x26,0xB9,0x05,0x4B,0x6E,0xA0,0xE2,0xE4,0x57,0xC2,0xB9,0xC1,0xB2,0x93,0x5F,0x09,0xD7,0x24,0xCB,0x4E,0x41,0x25,0x54,0x1D,0x62,0x3B,0x05,0x8D,0x52,0x57,0xAA,0xAD,0x10,0x24,0x26,0xE3,0xE1,0x36,0x5D,0x10,0x85,0xB4,0x97,0x85,0x72,0x41,0x14,0x52,0x5E,0x1A,0xCA,0xF9,0x91,0x6B,0x7A,0x5B,0xC4,0xE0,0x17,0x2D,0x54,0x1D,0x92,0x8C,0x1F,0x25,0x4B,0x8F,0xB2,0x16,0x41,0xA1,0x4A,0x3E,0xE6,0xFA,0xFF,0x01};
uint8_t spFOURTEEN[]  PROGMEM = {0x0C,0x58,0xAE,0x5C,0x01,0xD9,0x87,0x07,0x51,0xB7,0x25,0xB3,0x8A,0x15,0x2C,0xF7,0x1C,0x35,0x87,0x4D,0xB2,0xDD,0x53,0xCE,0x28,0x2B,0xC9,0x0E,0x97,0x2D,0xBD,0x2A,0x17,0x27,0x76,0x8E,0xD2,0x9A,0x6C,0x80,0x94,0x71,0x00,0x00,0x02,0xB0,0x58,0x58,0x00,0x9E,0x0B,0x0A,0xC0,0xB2,0xCE,0xC1,0xC8,0x98,0x7A,0x52,0x95,0x24,0x2B,0x11,0xED,0x36,0xD4,0x92,0xDC,0x4C,0xB5,0xC7,0xC8,0x53,0xF1,0x2A,0xE5,0x1A,0x17,0x55,0xC5,0xAF,0x94,0xBB,0xCD,0x1C,0x26,0xBF,0x52,0x9A,0x72,0x53,0x98,0xFC,0xC2,0x68,0xD2,0x4D,0x61,0xF0,0xA3,0x90,0xB6,0xD6,0x50,0xC1,0x8F,0x42,0xDA,0x4A,0x43,0x39,0x3F,0x48,0x2D,0x6B,0x33,0xF9,0xFF};
uint8_t spFIFTEEN[]   PROGMEM = {0x08,0xE8,0x2A,0x0D,0x01,0xDD,0xBA,0x31,0x60,0x6A,0xF7,0xA0,0xAE,0x54,0xAA,0x5A,0x76,0x97,0xD9,0x34,0x69,0xEF,0x32,0x1E,0x66,0xE1,0xE2,0xB3,0x43,0xA9,0x18,0x55,0x92,0x4E,0x37,0x2D,0x67,0x6F,0xDF,0xA2,0x5A,0xB6,0x04,0x30,0x55,0xA8,0x00,0x86,0x09,0xE7,0x00,0x01,0x16,0x17,0x05,0x70,0x40,0x57,0xE5,0x01,0xF8,0x21,0x34,0x00,0xD3,0x19,0x33,0x80,0x89,0x9A,0x62,0x34,0x4C,0xD5,0x49,0xAE,0x8B,0x53,0x09,0xF7,0x26,0xD9,0x6A,0x7E,0x23,0x5C,0x13,0x12,0xB3,0x04,0x9D,0x50,0x4F,0xB1,0xAD,0x14,0x15,0xC2,0xD3,0xA1,0xB6,0x42,0x94,0xA8,0x8C,0x87,0xDB,0x74,0xB1,0x70,0x59,0xE1,0x2E,0xC9,0xC5,0x81,0x5B,0x55,0xA4,0x4C,0x17,0x47,0xC1,0x6D,0xE3,0x81,0x53,0x9C,0x84,0x6A,0x46,0xD9,0x4C,0x51,0x31,0x42,0xD9,0x66,0xC9,0x44,0x85,0x29,0x6A,0x9B,0xAD,0xFF,0x07};
uint8_t spSIXTEEN[]   PROGMEM = {0x0A,0x58,0x5A,0x5D,0x00,0x93,0x97,0x0B,0x60,0xA9,0x48,0x05,0x0C,0x15,0xAE,0x80,0xAD,0x3D,0x14,0x30,0x7D,0xD9,0x50,0x92,0x92,0xAC,0x0D,0xC5,0xCD,0x2A,0x82,0xAA,0x3B,0x98,0x04,0xB3,0x4A,0xC8,0x9A,0x90,0x05,0x09,0x68,0x51,0xD4,0x01,0x23,0x9F,0x1A,0x60,0xA9,0x12,0x03,0xDC,0x50,0x81,0x80,0x22,0xDC,0x20,0x00,0xCB,0x06,0x3A,0x60,0x16,0xE3,0x64,0x64,0x42,0xDD,0xCD,0x6A,0x8A,0x5D,0x28,0x75,0x07,0xA9,0x2A,0x5E,0x65,0x34,0xED,0x64,0xBB,0xF8,0x85,0xF2,0x94,0x8B,0xAD,0xE4,0x37,0x4A,0x5B,0x21,0xB6,0x52,0x50,0x19,0xAD,0xA7,0xD8,0x4A,0x41,0x14,0xDA,0x5E,0x12,0x3A,0x04,0x91,0x4B,0x7B,0x69,0xA8,0x10,0x24,0x2E,0xE5,0xA3,0x81,0x52,0x90,0x94,0x5A,0x55,0x98,0x32,0x41,0x50,0xCC,0x93,0x2E,0x47,0x85,0x89,0x1B,0x5B,0x5A,0x62,0x04,0x44,0xE3,0x02,0x80,0x80,0x64,0xDD,0xFF,0x1F};
uint8_t spSEVENTEEN[] PROGMEM = {0x02,0x98,0x3A,0x42,0x00,0x5B,0xA6,0x09,0x60,0xDB,0x52,0x06,0x1C,0x93,0x29,0x80,0xA9,0x52,0x87,0x9A,0xB5,0x99,0x4F,0xC8,0x3E,0x46,0xD6,0x5E,0x7E,0x66,0xFB,0x98,0xC5,0x5A,0xC6,0x9A,0x9C,0x63,0x15,0x6B,0x11,0x13,0x8A,0x9C,0x97,0xB9,0x9A,0x5A,0x39,0x71,0xEE,0xD2,0x29,0xC2,0xA6,0xB8,0x58,0x59,0x99,0x56,0x14,0xA3,0xE1,0x26,0x19,0x19,0xE3,0x8C,0x93,0x17,0xB4,0x46,0xB5,0x88,0x71,0x9E,0x97,0x9E,0xB1,0x2C,0xC5,0xF8,0x56,0xC4,0x58,0xA3,0x1C,0xE1,0x33,0x9D,0x13,0x41,0x8A,0x43,0x58,0xAD,0x95,0xA9,0xDB,0x36,0xC0,0xD1,0xC9,0x0E,0x58,0x4E,0x45,0x01,0x23,0xA9,0x04,0x37,0x13,0xAE,0x4D,0x65,0x52,0x82,0xCA,0xA9,0x37,0x99,0x4D,0x89,0xBA,0xC0,0xBC,0x14,0x36,0x25,0xEA,0x1C,0x73,0x52,0x1D,0x97,0xB8,0x33,0xAC,0x0E,0x75,0x9C,0xE2,0xCE,0xB0,0xDA,0xC3,0x51,0x4A,0x1A,0xA5,0xCA,0x70,0x5B,0x21,0xCE,0x4C,0x26,0xD2,0x6C,0xBA,0x38,0x71,0x2E,0x1F,0x2D,0xED,0xE2,0x24,0xB8,0xBC,0x3D,0x52,0x88,0xAB,0x50,0x8E,0xA8,0x48,0x22,0x4E,0x42,0xA0,0x26,0x55,0xFD,0x3F};
uint8_t spEIGHTEEN[]  PROGMEM = {0x2E,0x9C,0xD1,0x4D,0x54,0xEC,0x2C,0xBF,0x1B,0x8A,0x99,0x70,0x7C,0xFC,0x2E,0x29,0x6F,0x52,0xF6,0xF1,0xBA,0x20,0xBF,0x36,0xD9,0xCD,0xED,0x0C,0xF3,0x27,0x64,0x17,0x73,0x2B,0xA2,0x99,0x90,0x65,0xEC,0xED,0x40,0x73,0x32,0x12,0xB1,0xAF,0x30,0x35,0x0B,0xC7,0x00,0xE0,0x80,0xAE,0xDD,0x1C,0x70,0x43,0xAA,0x03,0x86,0x51,0x36,0xC0,0x30,0x64,0xCE,0x4C,0x98,0xFB,0x5C,0x65,0x07,0xAF,0x10,0xEA,0x0B,0x66,0x1B,0xFC,0x46,0xA8,0x3E,0x09,0x4D,0x08,0x2A,0xA6,0x3E,0x67,0x36,0x21,0x2A,0x98,0x67,0x9D,0x15,0xA7,0xA8,0x60,0xEE,0xB6,0x94,0x99,0xA2,0x4A,0x78,0x22,0xC2,0xA6,0x8B,0x8C,0x8E,0xCC,0x4C,0x8A,0x2E,0x8A,0x4C,0xD3,0x57,0x03,0x87,0x28,0x71,0x09,0x1F,0x2B,0xE4,0xA2,0xC4,0xC5,0x6D,0xAD,0x54,0x88,0xB2,0x63,0xC9,0xF2,0x50,0x2E,0x8A,0x4A,0x38,0x4A,0xEC,0x88,0x28,0x08,0xE3,0x28,0x49,0xF3,0xFF};
uint8_t spNINETEEN[]  PROGMEM = {0xC2,0xEA,0x8A,0x95,0x2B,0x6A,0x05,0x3F,0x71,0x71,0x5F,0x0D,0x12,0xFC,0x28,0x25,0x62,0x35,0xF0,0xF0,0xB3,0x48,0x1E,0x0F,0xC9,0xCB,0x2F,0x45,0x7C,0x2C,0x25,0x1F,0xBF,0x14,0xB3,0x2C,0xB5,0x75,0xFC,0x5A,0x5C,0xA3,0x5D,0xE1,0xF1,0x7A,0x76,0xB3,0x4E,0x45,0xC7,0xED,0x96,0x23,0x3B,0x18,0x37,0x7B,0x18,0xCC,0x09,0x51,0x13,0x4C,0xAB,0x6C,0x4C,0x4B,0x96,0xD2,0x49,0xAA,0x36,0x0B,0xC5,0xC2,0x20,0x26,0x27,0x35,0x63,0x09,0x3D,0x30,0x8B,0xF0,0x48,0x5C,0xCA,0x61,0xDD,0xCB,0xCD,0x91,0x03,0x8E,0x4B,0x76,0xC0,0xCC,0x4D,0x06,0x98,0x31,0x31,0x98,0x99,0x70,0x6D,0x2A,0xA3,0xE4,0x16,0xCA,0xBD,0xCE,0x5C,0x92,0x57,0x28,0xCF,0x09,0x69,0x2E,0x7E,0xA5,0x3C,0x63,0xA2,0x30,0x05,0x95,0xD2,0x74,0x98,0xCD,0x14,0x54,0xCA,0x53,0xA9,0x96,0x52,0x50,0x28,0x6F,0xBA,0xCB,0x0C,0x41,0x50,0xDE,0x65,0x2E,0xD3,0x05,0x89,0x4B,0x7B,0x6B,0x20,0x17,0x44,0xAE,0xED,0x23,0x81,0x52,0x90,0x85,0x73,0x57,0xD0,0x72,0x41,0xB1,0x02,0xDE,0x2E,0xDB,0x04,0x89,0x05,0x79,0xBB,0x62,0xE5,0x76,0x11,0xCA,0x61,0x0E,0xFF,0x1F};
uint8_t spTWENTY[]    PROGMEM = {0x01,0x98,0xD1,0xC2,0x00,0xCD,0xA4,0x32,0x20,0x79,0x13,0x04,0x28,0xE7,0x92,0xDC,0x70,0xCC,0x5D,0xDB,0x76,0xF3,0xD2,0x32,0x0B,0x0B,0x5B,0xC3,0x2B,0xCD,0xD4,0xDD,0x23,0x35,0xAF,0x44,0xE1,0xF0,0xB0,0x6D,0x3C,0xA9,0xAD,0x3D,0x35,0x0E,0xF1,0x0C,0x8B,0x28,0xF7,0x34,0x01,0x68,0x22,0xCD,0x00,0xC7,0xA4,0x04,0xBB,0x32,0xD6,0xAC,0x56,0x9C,0xDC,0xCA,0x28,0x66,0x53,0x51,0x70,0x2B,0xA5,0xBC,0x0D,0x9A,0xC1,0xEB,0x14,0x73,0x37,0x29,0x19,0xAF,0x33,0x8C,0x3B,0xA7,0x24,0xBC,0x42,0xB0,0xB7,0x59,0x09,0x09,0x3C,0x96,0xE9,0xF4,0x58,0xFF,0x0F};
uint8_t spTHIRTY[]    PROGMEM = {0x08,0x98,0xD6,0x15,0x01,0x43,0xBB,0x0A,0x20,0x1B,0x8B,0xE5,0x16,0xA3,0x1E,0xB6,0xB6,0x96,0x97,0x3C,0x57,0xD4,0x2A,0x5E,0x7E,0x4E,0xD8,0xE1,0x6B,0x7B,0xF8,0x39,0x63,0x0D,0x9F,0x95,0xE1,0xE7,0x4C,0x76,0xBC,0x91,0x5B,0x90,0x13,0xC6,0x68,0x57,0x4E,0x41,0x8B,0x10,0x5E,0x1D,0xA9,0x44,0xD3,0xBA,0x47,0xB8,0xDD,0xE4,0x35,0x86,0x11,0x93,0x94,0x92,0x5F,0x29,0xC7,0x4C,0x30,0x0C,0x41,0xC5,0x1C,0x3B,0x2E,0xD3,0x05,0x15,0x53,0x6C,0x07,0x4D,0x15,0x14,0x8C,0xB5,0xC9,0x6A,0x44,0x90,0x10,0x4E,0x9A,0xB6,0x21,0x81,0x23,0x3A,0x91,0x91,0xE8,0xFF,0x01};
uint8_t spFOURTY[]    PROGMEM = {0x04,0x18,0xB6,0x4C,0x00,0xC3,0x56,0x30,0xA0,0xE8,0xF4,0xA0,0x98,0x99,0x62,0x91,0xAE,0x83,0x6B,0x77,0x89,0x78,0x3B,0x09,0xAE,0xBD,0xA6,0x1E,0x63,0x3B,0x79,0x7E,0x71,0x5A,0x8F,0x95,0xE6,0xA5,0x4A,0x69,0xB9,0x4E,0x8A,0x5F,0x12,0x56,0xE4,0x58,0x69,0xE1,0x36,0xA1,0x69,0x2E,0x2B,0xF9,0x95,0x93,0x55,0x17,0xED,0xE4,0x37,0xC6,0xBA,0x93,0xB2,0x92,0xDF,0x19,0xD9,0x6E,0xC8,0x0A,0xFE,0x60,0xE8,0x37,0x21,0xC9,0xF9,0x8D,0x61,0x5F,0x32,0x13,0xE7,0x17,0x4C,0xD3,0xC6,0xB1,0x94,0x97,0x10,0x8F,0x8B,0xAD,0x11,0x7E,0xA1,0x9A,0x26,0x92,0xF6,0xFF,0x01};
uint8_t spFIFTY[]     PROGMEM = {0x08,0xE8,0x2E,0x84,0x00,0x23,0x84,0x13,0x60,0x38,0x95,0xA5,0x0F,0xCF,0xE2,0x79,0x8A,0x8F,0x37,0x02,0xB3,0xD5,0x2A,0x6E,0x5E,0x93,0x94,0x79,0x45,0xD9,0x05,0x5D,0x0A,0xB9,0x97,0x63,0x02,0x74,0xA7,0x82,0x80,0xEE,0xC3,0x10,0xD0,0x7D,0x28,0x03,0x6E,0x14,0x06,0x70,0xE6,0x0A,0xC9,0x9A,0x4E,0x37,0xD9,0x95,0x51,0xCE,0xBA,0xA2,0x14,0x0C,0x81,0x36,0x1B,0xB2,0x5C,0x30,0x38,0xFA,0x9C,0xC9,0x32,0x41,0xA7,0x18,0x3B,0xA2,0x48,0x04,0x05,0x51,0x4F,0x91,0x6D,0x12,0x04,0x20,0x9B,0x61,0x89,0xFF,0x1F};
uint8_t spGOOD[]      PROGMEM = {0x0A,0x28,0xCD,0x34,0x20,0xD9,0x1A,0x45,0x74,0xE4,0x66,0x24,0xAD,0xBA,0xB1,0x8C,0x9B,0x91,0xA5,0x64,0xE6,0x98,0x21,0x16,0x0B,0x96,0x9B,0x4C,0xE5,0xFF,0x01};
uint8_t spMORNING[]   PROGMEM = {0xCE,0x08,0x52,0x2A,0x35,0x5D,0x39,0x53,0x29,0x5B,0xB7,0x0A,0x15,0x0C,0xEE,0x2A,0x42,0x56,0x66,0xD2,0x55,0x2E,0x37,0x2F,0xD9,0x45,0xB3,0xD3,0xC5,0xCA,0x6D,0x27,0xD5,0xEE,0x50,0xF5,0x50,0x94,0x14,0x77,0x2D,0xD8,0x5D,0x49,0x92,0xFD,0xB1,0x64,0x2F,0xA9,0x49,0x0C,0x93,0x4B,0xAD,0x19,0x17,0x3E,0x66,0x1E,0xF1,0xA2,0x5B,0x84,0xE2,0x29,0x8F,0x8B,0x72,0x10,0xB5,0xB1,0x2E,0x4B,0xD4,0x45,0x89,0x4A,0xEC,0x5C,0x95,0x14,0x2B,0x8A,0x9C,0x34,0x52,0x5D,0xBC,0xCC,0xB5,0x3B,0x49,0x69,0x89,0x87,0xC1,0x98,0x56,0x3A,0x21,0x2B,0x82,0x67,0xCC,0x5C,0x85,0xB5,0x4A,0x8A,0xF6,0x64,0xA9,0x96,0xC4,0x69,0x3C,0x52,0x81,0x58,0x1C,0x97,0xF6,0x0E,0x1B,0xCC,0x0D,0x42,0x32,0xAA,0x65,0x12,0x67,0xD4,0x6A,0x61,0x52,0xFC,0xFF};
uint8_t spAFTERNOON[] PROGMEM = {0xC7,0xCE,0xCE,0x3A,0xCB,0x58,0x1F,0x3B,0x07,0x9D,0x28,0x71,0xB4,0xAC,0x9C,0x74,0x5A,0x42,0x55,0x33,0xB2,0x93,0x0A,0x09,0xD4,0xC5,0x9A,0xD6,0x44,0x45,0xE3,0x38,0x60,0x9A,0x32,0x05,0xF4,0x18,0x01,0x09,0xD8,0xA9,0xC2,0x00,0x5E,0xCA,0x24,0xD5,0x5B,0x9D,0x4A,0x95,0xEA,0x34,0xEE,0x63,0x92,0x5C,0x4D,0xD0,0xA4,0xEE,0x58,0x0C,0xB9,0x4D,0xCD,0x42,0xA2,0x3A,0x24,0x37,0x25,0x8A,0xA8,0x8E,0xA0,0x53,0xE4,0x28,0x23,0x26,0x13,0x72,0x91,0xA2,0x76,0xBB,0x72,0x38,0x45,0x0A,0x46,0x63,0xCA,0x69,0x27,0x39,0x58,0xB1,0x8D,0x60,0x1C,0x34,0x1B,0x34,0xC3,0x55,0x8E,0x73,0x45,0x2D,0x4F,0x4A,0x3A,0x26,0x10,0xA1,0xCA,0x2D,0xE9,0x98,0x24,0x0A,0x1E,0x6D,0x97,0x29,0xD2,0xCC,0x71,0xA2,0xDC,0x86,0xC8,0x12,0xA7,0x8E,0x08,0x85,0x22,0x8D,0x9C,0x43,0xA7,0x12,0xB2,0x2E,0x50,0x09,0xEF,0x51,0xC5,0xBA,0x28,0x58,0xAD,0xDB,0xE1,0xFF,0x03};
uint8_t spEVENING[]   PROGMEM = {0xCD,0x6D,0x98,0x73,0x47,0x65,0x0D,0x6D,0x10,0xB2,0x5D,0x93,0x35,0x94,0xC1,0xD0,0x76,0x4D,0x66,0x93,0xA7,0x04,0xBD,0x71,0xD9,0x45,0xAE,0x92,0xD5,0xAC,0x53,0x07,0x6D,0xA5,0x76,0x63,0x51,0x92,0xD4,0xA1,0x83,0xD4,0xCB,0xB2,0x51,0x88,0xCD,0xF5,0x50,0x45,0xCE,0xA2,0x2E,0x27,0x28,0x54,0x15,0x37,0x0A,0xCF,0x75,0x61,0x5D,0xA2,0xC4,0xB5,0xC7,0x44,0x55,0x8A,0x0B,0xA3,0x6E,0x17,0x95,0x21,0xA9,0x0C,0x37,0xCD,0x15,0xBA,0xD4,0x2B,0x6F,0xB3,0x54,0xE4,0xD2,0xC8,0x64,0xBC,0x4C,0x91,0x49,0x12,0xE7,0xB2,0xB1,0xD0,0x22,0x0D,0x9C,0xDD,0xAB,0x62,0xA9,0x38,0x53,0x11,0xA9,0x74,0x2C,0xD2,0xCA,0x59,0x34,0xA3,0xE5,0xFF,0x03};
uint8_t spPAUSE1[]    PROGMEM = {0x00,0x00,0x00,0x00,0xFF,0x0F};
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
void loop()
{
  struct tm tmstruct ;
  tmstruct.tm_year = 0;
  GetLocalTime(&tmstruct, 5000);
  Serial.printf("\nNow is : %d-%02d-%02d %02d:%02d:%02d\n",
                tmstruct.tm_year + 1900, tmstruct.tm_mon + 1,
                tmstruct.tm_mday, tmstruct.tm_hour,
                tmstruct.tm_min, tmstruct.tm_sec);
  sayTime(tmstruct.tm_hour, tmstruct.tm_min, talkie);
  delay(1000);
}

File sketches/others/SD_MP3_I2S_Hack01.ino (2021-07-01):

// ESP32-A1S module demo
// display directory contents
// playback mp3 files from root directory of an SD card
// to I2S AC101 audio device
//
// requires audio library:  https://github.com/earlephilhower/ESP8266Audio
// requires AC101 library:  https://github.com/marcel-licence/AC101
//
// note: this doesn't work properly - it was hacked together from other esp8266 audio player examples
//       it will skip loading the first mp3 and start from the second, play it, then give an error buflen 0
//       but it does read from SD and play over I2S, which is what the goal was.
// Gadget Reboot

//Michael-Nolan - I took the SD_MP3_I2S and extended the functionality to 3 buttons MP3 player
//                Buttons may map differently according to board ... Vol Down Key3 - hold for 1.5sec back track
//                          Play/Pause - some interest in using seek to resume file Key 4
//                          Volume Up Key 4 - hold 1.5 sec for next track
//                Plenty of Serial print of what is going on for debug - interest
//Hack v00 -      I worked on the play button, stop and start the id3/mp3 playing including capture pos
//                seek back to the pos after re-opening the file (check) and start playing from there works.
/*     v01 -      Add the volume keys on 18/19 (key5 and 3) - when I used the 13 (key2) it seemed to
                  mess up SD card communications 13 is defined as SS - 3 parameters used 
                  for SDSPI.begin(sck, miso, mosi, -1);
                  the SS used SD.begin(ss, SDSPI); - i don't see where SD is allocated as an object ...
                  So no, don't use 13 because its connected to SD - which is a stupid overlap with a key ... sheesh
                  Timing for long and shorter press functions like volume change or next prev track
                  Files array of file from directory
       v02 -      Better directory handing and refactoring for multiple file types
*/
#include <Arduino.h>
#include "AudioFileSourceSD.h"
#include "AudioFileSourceID3.h"
#include "AudioGeneratorMP3.h"
#include "AudioOutputI2S.h"
#include "AC101.h"

// ESP32 pins for AC101 chip
#define IIS_SCLK                    27
#define IIS_LCLK                    26
#define IIS_DSIN                    25

#define IIC_CLK                     32
#define IIC_DATA                    33

//Sat Jun 19 2021
//Michael hack - take some code from ESP32AudioKit to add key input so I can start
// coding up features and tests
#define PIN_PLAY                    (23)      // KEY 4
#define PIN_VOL_UP                  (18)      // KEY 5
#define PIN_VOL_DOWN                (19)       // KEY 3
#define MAX_FILES 20

// You may need a fast SD card. Set this as high as it will work (40MHz max).
#define SPI_SPEED SD_SCK_MHZ(40)

static AC101 ac;

File file, currentFile, dir;
String filenames[MAX_FILES]; // so we can facilitate fwd/back tracks lets make an array of files
uint8_t fileIndex = 0;  // where we are as we write the files or play the files
uint8_t lastFileNumber = 0;
AudioFileSourceID3 *id3;
AudioGeneratorMP3 *mp3;
AudioOutputI2S *out;
AudioFileSourceSD *source = NULL;

// SD card connected to these pins
// using HSPI channel on ESP32
SPIClass SDSPI(HSPI);

#define sck  14
#define miso  2
#define mosi 15
#define ss   13

static uint8_t volume = 40;
const uint8_t volume_step = 2;
unsigned long debounce = 0;
unsigned long upPressedTime, downPressedTime;
bool  playState = LOW;
String currentFilename = "";
uint32_t currentSongPos;



void setup()
{
  Serial.begin(115200);

  Serial.printf("Init AC101 codec ");
  while (not ac.begin(IIC_DATA, IIC_CLK))
  {
    Serial.printf(".");
    delay(500);
  }
  Serial.printf("OK\n");

  ac.SetVolumeSpeaker(0);
  ac.SetVolumeHeadphone(volume);

  audioLogger = &Serial;
  source = new AudioFileSourceSD();
  id3 = NULL;
  mp3 = new AudioGeneratorMP3();
  out = new AudioOutputI2S();

  
   
  // define I2S pins for AC101
  out->SetPinout(IIS_SCLK /*bclkPin*/, IIS_LCLK /*wclkPin*/, IIS_DSIN /*doutPin*/);

  // init SD card
  SDSPI.begin(sck, miso, mosi, -1);
  SD.begin(ss, SDSPI);

  dir  = SD.open("/");

  // Configure keys on ESP32 Audio Kit board
  pinMode(PIN_PLAY, INPUT_PULLUP);
  pinMode(PIN_VOL_UP, INPUT_PULLUP);
  pinMode(PIN_VOL_DOWN, INPUT_PULLUP);


  Serial.println("Directory file list:\n");
  readDirectory(dir, 4);
  
  Serial.println("\nEnd of directory.");
  
  fileIndex = 0;
  dir.rewindDirectory();
}
/* key pressed function stolen from ESP32Audio Kit
 *  
 */
bool pressed( const int pin )
{
  if (millis() > (debounce + 500))
  {
      if (digitalRead(pin) == LOW)
      {
        debounce = millis();
        return true;
      }
  }
  return false;
}

bool stillPressed(const int pin)
{
  return (digitalRead(pin) == LOW);
}

void loop()
{
  String fileName = "";

  if (mp3->isRunning()) {
    if (!mp3->loop()) 
    {
      mp3->stop();
      fileIndex++;
      Serial.printf("Finished playback of '%s'...\n", currentFilename.c_str());
    }
  }
  else if(playState){
    // Find MP3 file and play it
    constrain(fileIndex,0,lastFileNumber);
    while ((fileIndex < lastFileNumber) && SD.exists(filenames[fileIndex])) {     
      file = SD.open(filenames[fileIndex]);
   
      printDirectory();
      if (String(file.name()).endsWith(".mp3")) {
        if (source->open(file.name())) {
          currentFilename = String(file.name());
          currentFile = file;
          
          break;
        } 
      } else {
          fileIndex++;
          if (fileIndex >= lastFileNumber)
          currentFilename = "";
          
        }
      
      
    } //close while
    if(source->isOpen()) // this check stops trying to play unopened unloadable + prevent not ready buzz sound
      playSourceAsID3(); // will take current filename and source that was opened and assume MP3 

  }//close if
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
